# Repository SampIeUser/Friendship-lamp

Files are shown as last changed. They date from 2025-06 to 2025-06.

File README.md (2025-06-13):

# Friendship lamp
📡 Lamp on ESP32.

## Table of contents
 + [1. Description](#1_parag);
 + [2. Components to build](#2_parag);
 + [3. Connection scheme](#3_parag);
 + [4. Assembly](#4_parag);
 + [5. Operation modes](#5_parag);
 + [6. Demonstration](#6_parag);

## 	1. Description
Lamps are connected through internet and emitting same color at the same time. Color is changed using 3 potentiometers,
and any combination of RGB can be selected.
It is required to have MQTT server, othervise lamps won't be connected. MQTT server may be random external
free service or your own. I use Mosquitto for this purpose.  

This lamp is meant to be made in several pcs. 

## 	2. Components to build
- 22 AWG wires 1.5A
- Led diodes (i used white, blue and green, due to their operational)
- Adressable 5v led strip (WS2812). (due to operation voltage)
- ESP32
- Accumulator (I used [This](https://www.aliexpress.com/item/1005006116209915.html) 18650, 5V6800 XH2.54. (21mm x 42mm x 74mm))
- Resistor 470Ω
- Resistor 100Ω x3
- Switch button
- Potentiometer 5-10kΩ x3 (i used 10kΩ)
- 3D printer (or something that you will use as case)

##  3. Connection scheme

- D4 - Blue LED + 100Ω resistor
- D5 - Green LED + 100Ω resistor
- D18 - White LED + 100Ω resistor
- Potentiometer_GREEN - ESP32 (D32)
- Potentiometer_RED - ESP32 (D34)
- Potentiometer_BLUE ESP32 (D35)
- ALL Potentiometer VCC pins (+) to ESP32 (3.3v)
- Button - between ESP32 (VIN) and Accumulator (+)
- LED Strip (+) goes to Accumulator (+) (**after the button. may go to VIN**)
- LED Strip (data) goes to ESP32 D23 (**through 470Ω resistor**)
- Ground is shared between all components and meets in ESP32's GND pin. (GND and "-" things)

##  4. Assembly
Models i used are in "3D Models" folder. I used Creality Ender 3V3 SE printer.  
"fit_test.stl" Represents the size of cylinder which is needed to be inserted into the lamp. There is no "lamp" itself, because 
i used some random food container and sanded both sides to make it diffuse light. "fit_test" will help you to print/make your own.  
"Light diffuser" is used to additionaly diffuse the light and protect strip from physical damage. It can be easily removed/put on.
Must be printed with transparent filament.
<details>
  <summary>Assembly</summary>

  Assembly
</details>

##  5. Operation modes
1. Offline mode  
  1.1 When turned on, lamp will try to connect to wifi (blue led will be lit). If it has no credentials, after 5 seconds it will turn into server and host it's own wifi.
It will be called "ESP32 lamp" and will not have password. White led will be lit. You must connect to it, go to 192.168.4.1 and enter WiFi credentials,
where lamp shall connect to. After this, you shall restart the lamp and it will connect to wifi.  
  1.2 If you don't want lamp to go online, just start use it and white led will turn off.

2. Online mode  
    2.1 After connecting to Wifi, blue led will turn off. Lamp will try to connect to MQTT server. If there is no connection between
   MQTT server and lamp, green led will be lit. If everything ok - all diodes will be off. When you turn the potentiometer, lamp will change
    it's color (this is useful when you have a high ping). After changing it's color, new setting will be sent to MQTT server. Lamp will set color received from MQTT server and notify you about it,
    by blinking with white and blue leds. If you see no blinking - color was not received from MQTT server.

##  6. Demonstration
Demonstration. First one connected to my home wifi, second is to other persons home wifi. Demonstration through video call.
<details>
  <summary>Gif 1</summary>
  
gif 1
</details>
<details>
  <summary>Gif 2</summary>
  
 gif 2
</details>

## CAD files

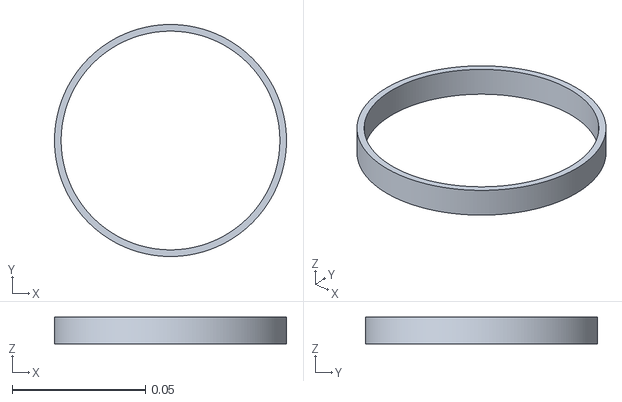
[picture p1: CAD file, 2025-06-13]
3D Models/fit_test.stl
0.087 x 0.087 x 0.01

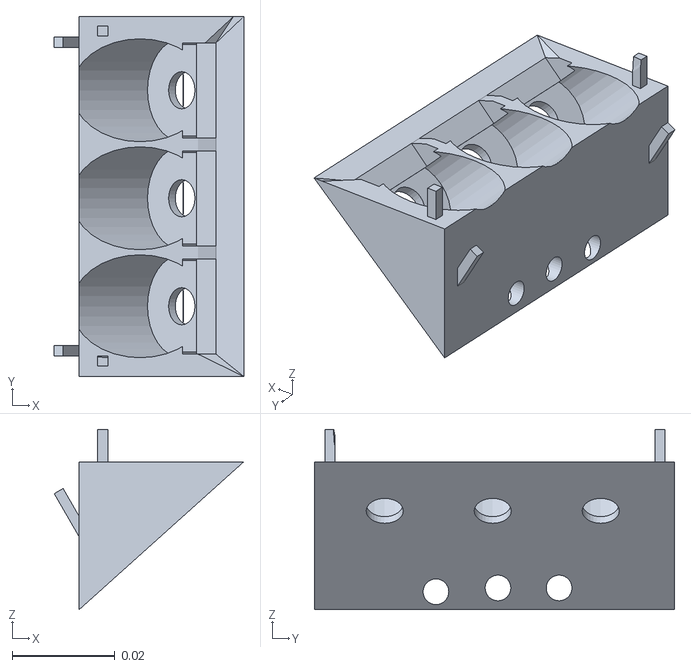
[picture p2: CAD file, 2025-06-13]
3D Models/Potentiometer panel (top).stl
0.0369 x 0.07 x 0.035

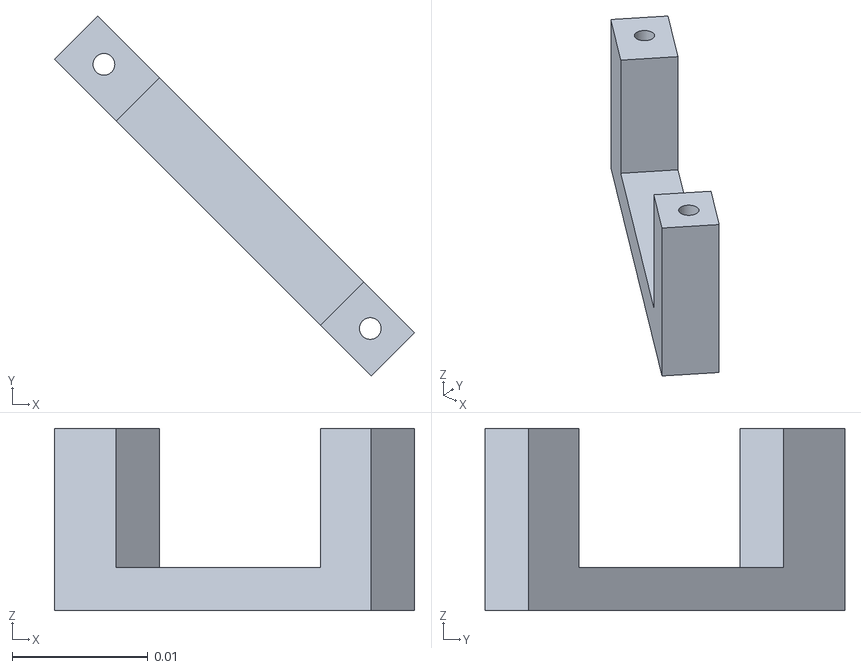
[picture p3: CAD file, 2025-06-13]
3D Models/accum_holder.stl
0.0265 x 0.0265 x 0.0134

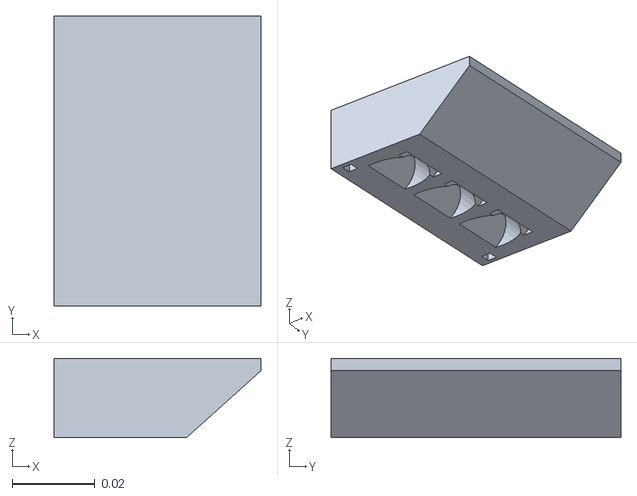
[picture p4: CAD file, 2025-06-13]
3D Models/Potentiometer panel (bottom).stl
0.05 x 0.07 x 0.0192

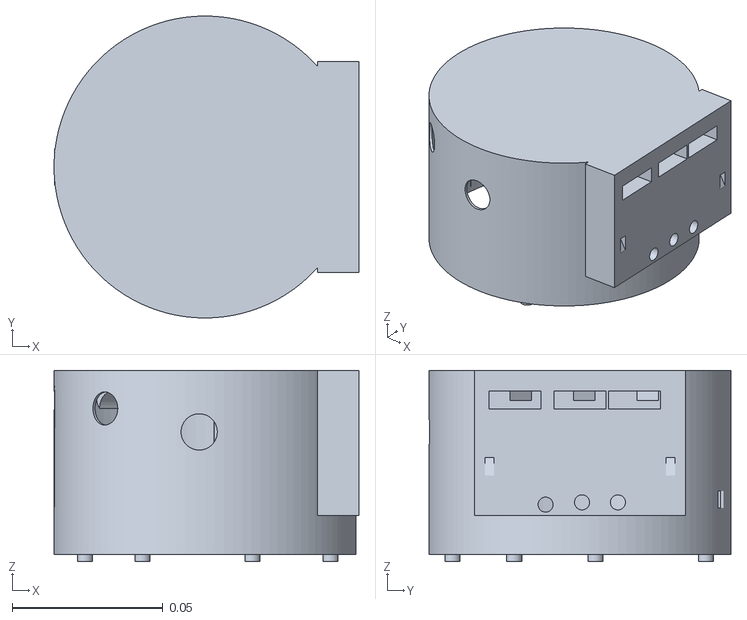
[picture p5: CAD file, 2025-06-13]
3D Models/base.stl
0.101 x 0.1 x 0.0633

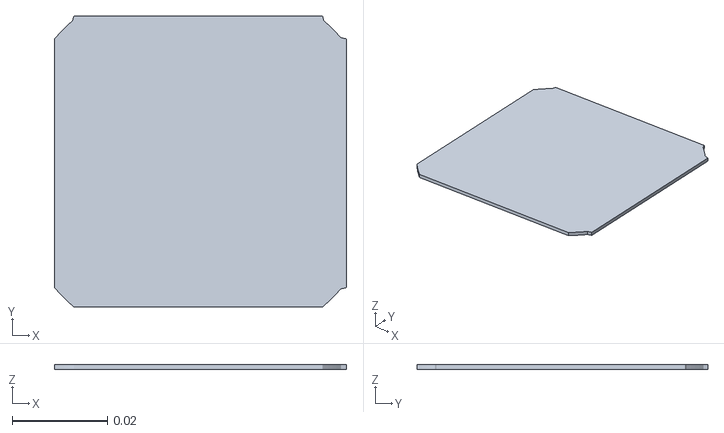
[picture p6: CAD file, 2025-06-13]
3D Models/Light diffuser.stl
0.0615 x 0.0612 x 0.001

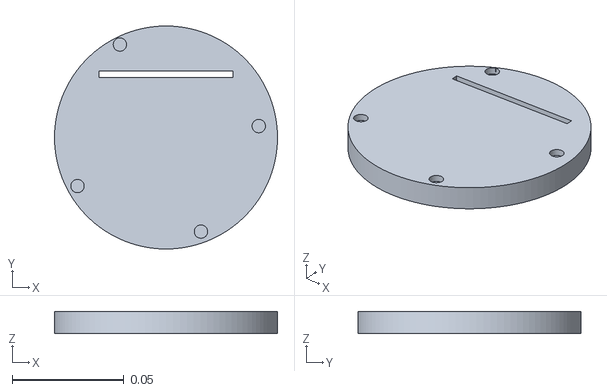
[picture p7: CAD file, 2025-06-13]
3D Models/cup.stl
0.1 x 0.1 x 0.01

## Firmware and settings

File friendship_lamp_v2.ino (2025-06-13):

#include <Arduino.h>
#include "FS.h"
#include "SPIFFS.h"
#include <WiFi.h>
#include <WebServer.h>
#include <PubSubClient.h> // MQTT
#include <Adafruit_NeoPixel.h> // LED strip


/*
██╗███╗░░██╗██╗████████╗██╗░█████╗░██╗░░░░░██╗███████╗░█████╗░████████╗██╗░█████╗░███╗░░██╗
██║████╗░██║██║╚══██╔══╝██║██╔══██╗██║░░░░░██║╚════██║██╔══██╗╚══██╔══╝██║██╔══██╗████╗░██║
██║██╔██╗██║██║░░░██║░░░██║███████║██║░░░░░██║░░███╔═╝███████║░░░██║░░░██║██║░░██║██╔██╗██║
██║██║╚████║██║░░░██║░░░██║██╔══██║██║░░░░░██║██╔══╝░░██╔══██║░░░██║░░░██║██║░░██║██║╚████║
██║██║░╚███║██║░░░██║░░░██║██║░░██║███████╗██║███████╗██║░░██║░░░██║░░░██║╚█████╔╝██║░╚███║
╚═╝╚═╝░░╚══╝╚═╝░░░╚═╝░░░╚═╝╚═╝░░╚═╝╚══════╝╚═╝╚══════╝╚═╝░░╚═╝░░░╚═╝░░░╚═╝░╚════╝░╚═╝░░╚══╝
*/

// modes
bool isServerStarted = false;


// 
extern bool initStorage();
extern bool writeData(const char* path, const String& data);
extern String readData(const char* path);
extern void WifiConnect(); // Connection to Wi-Fi

//Server initialisation
extern WebServer server;

// LED pins
const int LED_PIN_CONNECTED = 4;  // Blue LED
const int LED_PIN_FAILED = 18;    // White LED
const int LED_PIN_WORK = 5; // Green LED

// MQTT server settings
#define MQTT_SERVER "domain.net"
#define MQTT_PORT 12345
#define MQTT_USER "user"
#define MQTT_PASSWORD "passwd"
#define MQTT_TOPIC "topic/subtopic/verysubtopic"

WiFiClient espClient;
PubSubClient client(espClient);
String inputString = "";  // serial buffer
bool stringComplete = false;  // 

//stopwatch 
unsigned long previousMillis = 0;  // 
const long interval = 10000;  // 
unsigned long startMillis = 0;  // 

//import from other tab (MQTT)
extern void reconnectMQTT(); //MQTT connection
extern void mqttCallback(char* topic, byte* payload, unsigned int length); //получение с ообщений. поменять с войда на другое
extern void serialEvent(); // read from serial


//
//potentiometers
#define POTENTIOMETER_PIN_R 34  // 
#define POTENTIOMETER_PIN_G 32  // 
#define POTENTIOMETER_PIN_B 35  // 

#define LED_PIN 23  // LED strip pin
#define LED_COUNT 15  // strip LED count

Adafruit_NeoPixel strip(LED_COUNT, LED_PIN, NEO_RGB + NEO_KHZ800);

// potentiometer data store
int ref_red = 0;
int ref_green = 0;
int ref_blue = 0;
bool isUpdateNeeded = false;
String unite_colors = "";  // to sending colors

byte noise_corr = 2; // noise correction 
bool isWhiteDiodeNeeded = false;

#define NUM_SAMPLES 10
int valuesR[NUM_SAMPLES] = {0};
int valuesG[NUM_SAMPLES] = {0};
int valuesB[NUM_SAMPLES] = {0};
int index2 = 0;

// potentiometer smoothed value
int getSmoothedValue(int *values) {
    int sum = 0;
    for (int i = 0; i < NUM_SAMPLES; i++) {
        sum += values[i];
    }
    return sum / NUM_SAMPLES;
}


/*
░██████╗███████╗████████╗██╗░░░██╗██████╗░
██╔════╝██╔════╝╚══██╔══╝██║░░░██║██╔══██╗
╚█████╗░█████╗░░░░░██║░░░██║░░░██║██████╔╝
░╚═══██╗██╔══╝░░░░░██║░░░██║░░░██║██╔═══╝░
██████╔╝███████╗░░░██║░░░╚██████╔╝██║░░░░░
╚═════╝░╚══════╝░░░╚═╝░░░░╚═════╝░╚═╝░░░░░
*/


void setup() {
  delay(1000); // startup delay
  Serial.begin(115200);


  pinMode(LED_PIN_CONNECTED, OUTPUT); // Blue
  pinMode(LED_PIN_FAILED, OUTPUT); // White
  pinMode(LED_PIN_WORK, OUTPUT);  // Green
  

  // SPIFFS initialization
  if (!initStorage()) {
    Serial.println("SPIFFS initialization error");
    return;
  }

  // Wi-Fi
  WifiConnect();

 
  // setup of the MQTT s
  client.setServer(MQTT_SERVER, MQTT_PORT);
  client.setCallback(mqttCallback);  // 
  client.setSocketTimeout(5);  // 
  client.setKeepAlive(60);  // 

  


  // led strip
    strip.begin();
    strip.show(); // 
    pinMode(POTENTIOMETER_PIN_R, INPUT);
    pinMode(POTENTIOMETER_PIN_G, INPUT);
    pinMode(POTENTIOMETER_PIN_B, INPUT);

}

void loop() {

  if (isServerStarted) // Server is started. Local mode is active
  {
    server.handleClient();  // 

      //Local use mode

      // 
    int valueR = analogRead(POTENTIOMETER_PIN_R);  
    int valueG = analogRead(POTENTIOMETER_PIN_G);  
    int valueB = analogRead(POTENTIOMETER_PIN_B);  
    // Cut the brihtness (0-152). Values over 152 should not be used, because strip will warm up too much.
    valueR = valueR/27;
    valueG = valueG/27;
    valueB = valueB/27;

    // low value noise correction   
    if (valueR < 10) {valueR = 0;}
    if (valueG < 10) {valueG = 0;}
    if (valueB < 10) {valueB = 0;}

    strip.fill(strip.Color(valueR, valueG, valueB)); // (R, G, B)
    strip.show();
    
    //Turn off the white LED if lamp is used. 

    
    if(isWhiteDiodeNeeded)
    {
      if (valueR > ref_red+noise_corr || valueR < ref_red-noise_corr)     
      {digitalWrite(LED_PIN_FAILED, LOW);}
      //зелёный
      if (valueG > ref_green+noise_corr || valueG < ref_green-noise_corr)     
      {digitalWrite(LED_PIN_FAILED, LOW);}
      //синий
      if (valueB > ref_blue+noise_corr || valueB < ref_blue-noise_corr)
     {digitalWrite(LED_PIN_FAILED, LOW);}
    }
  //
 




  } // end of local mode

  else // local server is not started, online mode is on
  {
  // MQTT connection check
  if (!client.connected()) {
    digitalWrite(LED_PIN_WORK, HIGH);  // Show that MQTT is not connected
    reconnectMQTT();
  }
  else
  {
    digitalWrite(LED_PIN_WORK, LOW);  // MQTT is connected
  }
  client.loop();  // 

  // 
  if (stringComplete) {
    Serial.print("Sending: ");
    Serial.println(inputString);

    client.publish(MQTT_TOPIC, inputString.c_str());
    inputString = "";  // Очищаем буфер
    stringComplete = false;
  }

    // strip
    int valueR = analogRead(POTENTIOMETER_PIN_R);  
    int valueG = analogRead(POTENTIOMETER_PIN_G); 
    int valueB = analogRead(POTENTIOMETER_PIN_B);  
    // Cut the brihtness (0-152). Values over 152 should not be used, because strip will warm up too much.
    valueR = valueR/27;
    valueG = valueG/27;
    valueB = valueB/27;
    

    // save last values to array
    valuesR[index2] = valueR;
    valuesG[index2] = valueG;
    valuesB[index2] = valueB;
    
    index2 = (index2 + 1) % NUM_SAMPLES; 
    valueR = getSmoothedValue(valuesR);
    valueG = getSmoothedValue(valuesG);
    valueB = getSmoothedValue(valuesB);

    // low values noise correction
    if (valueR < 10) {valueR = 0;}
    if (valueG < 10) {valueG = 0;}
    if (valueB < 10) {valueB = 0;}

. 
  //red
  if (valueR > ref_red+noise_corr || valueR < ref_red-noise_corr)
      {ref_red = valueR; // 
      isUpdateNeeded = true;} // 
  else
      {valueR = ref_red;} // 
  //green
  if (valueG > ref_green+noise_corr || valueG < ref_green-noise_corr)
      {ref_green = valueG;
      isUpdateNeeded = true;} // 
  else
      {valueG = ref_green;}
  //blue
  if (valueB > ref_blue+noise_corr || valueB < ref_blue-noise_corr)
      {ref_blue = valueB;
      isUpdateNeeded = true;} //
  else
      {valueB = ref_blue;}

  //T
  if (isUpdateNeeded) // 
  {
    //first lamp be updated locally, then data will be sent to MQTT server and readed from it (in case if ping is high, it will make changins smooth)
    strip.fill(strip.Color(valueR, valueG, valueB)); //(R, G, B)
    strip.show();


    unite_colors = "Color," + String(valueG) + "," + String(valueR) + "," + String(valueB);
    client.publish(MQTT_TOPIC, unite_colors.c_str());    
    isUpdateNeeded = false; 
  }
  else
  {
    

    

  }
  } // end isServerStarted
  


   
  
} //loop end





// 
void mqttCallback(char* topic, byte* payload, unsigned int length) {

  // 
  String message = "";
  for (unsigned int i = 0; i < length; i++) {
    message += (char)payload[i];  // 
  }
  
  // if message starts with "Color"
    if (message.startsWith("Color")) {
        // split by commas
        int firstCommaIndex = message.indexOf(','); // 
        int secondCommaIndex = message.indexOf(',', firstCommaIndex + 1); //
        int thirdCommaIndex = message.indexOf(',', secondCommaIndex + 1); // 

        // get colors
        String redStr = message.substring(firstCommaIndex + 1, secondCommaIndex); // red
        String greenStr = message.substring(secondCommaIndex + 1, thirdCommaIndex); // green
        String blueStr = message.substring(thirdCommaIndex + 1); // blue

        //
        int red = redStr.toInt();
        int green = greenStr.toInt();
        int blue = blueStr.toInt();

        // check the range (0-255)
        if (red >= 0 && red <= 160 && green >= 0 && green <= 160 && blue >= 0 && blue <= 160) {
            // 
            //if data from MQTT, make the 2 diodes blink so user knows it's working
                   
             digitalWrite(LED_PIN_CONNECTED, HIGH); // blue
             digitalWrite(LED_PIN_FAILED, HIGH); // white

            
            strip.fill(strip.Color(green, red, blue)); //  (R, G, B)
            strip.show();

             digitalWrite(LED_PIN_CONNECTED, LOW); // blue
             digitalWrite(LED_PIN_FAILED, LOW); // white   

            Serial.println(String(red) + "//" + String(green) + "//" + String(blue));
        } else {
            Serial.println("Received invalid RGB values.");
        }
    } else {
        Serial.println(message); // it's not color
    }
  
}

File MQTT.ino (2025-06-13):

// connect to MQTT
void reconnectMQTT() {
  
  while (!client.connected()) {
    
    Serial.print("Connection to MQTT...");
    

    // П
    uint64_t chipId = ESP.getEfuseMac();  // get ESP32 MAC
    String clientId = "ESP32Client_" + String(chipId, DEC);  // 

    // connect to MQTT via unique clientID
    if (client.connect(clientId.c_str(), MQTT_USER, MQTT_PASSWORD)) {
      Serial.println("Connected to MQTT");

      // subscription to topic
      if (client.subscribe(MQTT_TOPIC)) {
        Serial.println("Subscribed to topic");
      } else {
        Serial.println("Subscription error");
      }
    } else {
      Serial.print("Conect error: ");
      Serial.print(client.state());
      Serial.println(" Rejoining in 1 secods...");
      delay(1000);  //
    }
  }
}


// read data from serial Serial
void serialEvent() {
  while (Serial.available()) {
    char inChar = (char)Serial.read();
    inputString += inChar;
    if (inChar == '\n') {  // 
      stringComplete = true;
    }
  }
}
